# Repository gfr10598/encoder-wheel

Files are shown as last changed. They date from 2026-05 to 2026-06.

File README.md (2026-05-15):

# Encoder Wheel

A parametric design repository for **magnetic rotary encoder wheels**.

The wheel holds *N* (a multiple of 12) rectangular permanent magnets in a
radial arrangement.  A Hall-effect sensor reads the alternating North/South
poles as the wheel rotates, giving a high-resolution angle or speed signal.

This repository provides Python scripts that generate ready-to-fabricate files
for three different manufacturing processes:

| Fabrication method | Script | Output format |
|---|---|---|
| **Laser cutter** | `scripts/cad/generate_laser.py` | SVG |
| **CNC mill** | `scripts/cad/generate_cnc.py` | DXF (R12) |
| **3-D printer** | `scripts/cad/generate_3d.py` | OpenSCAD (`.scad`) |

All scripts share a common geometry core (`scripts/common.py`) and accept the
same magnet-dimension and pole-count parameters, so you can swap fabrication
methods without re-calculating anything.

---

## Contents

```raw
encoder-wheel/
├── scripts/
│   ├── common.py                       shared geometry calculations
│   ├── common_config.py                shared config loading
│   ├── cad/                            CAD fabrication generators
│   │   ├── generate_laser.py           → SVG for laser cutting
│   │   ├── generate_cnc.py             → DXF for CNC milling
│   │   ├── generate_3d.py              → OpenSCAD for 3-D printing
│   │   └── generate_half_ring_docs.py  → SVG design-reference documentation
│   └── magnetic/                       magnetic field analysis & validation
│       ├── magnet.py                   MagnetCorners class & Aharoni formula
│       ├── test_kj_validation.py       K&J website benchmark (1.6% error)
│       ├── test_single_magnet_vs_kj.py validation test harness
│       └── simulation.py               full encoder wheel simulation
├── AGENTS.md                       AI-agent-facing design notes
├── examples/
│   ├── encoder_wheel_12pole_laser.svg
│   ├── encoder_wheel_24pole_laser.svg
│   ├── encoder_wheel_108pole_laser.svg
│   ├── encoder_wheel_12pole_cnc.dxf
│   ├── encoder_wheel_108pole_cnc.dxf
│   ├── encoder_wheel_12pole_3d.scad        (back plate + tabs)
│   ├── encoder_wheel_108pole_3d.scad       (back plate + tabs)
│   ├── encoder_wheel_12pole_3d_frontface.scad
│   └── encoder_wheel_12pole_3d_steelclip.scad
└── images/

    ├── top_view.svg```

    ├── cross_section.svg    └── half_ring_over_magnets_perspective.svg

    ├── geometry.svg    ├── half_ring_over_magnets_top_view.svg
    ├── half_ring_over_magnets_cross_section.svg

---

## Half-ring cover design notes

The repository also includes a documentation-only capture of the requested
**10 in half-ring over magnets** concept for future CAD work:

- agent/design notes: [`AGENTS.md`](AGENTS.md)
- generated reference drawings:
  - `images/half_ring_over_magnets_cross_section.svg`
  - `images/half_ring_over_magnets_top_view.svg`
  - `images/half_ring_over_magnets_perspective.svg`

Regenerate those drawings with:

```bash
python scripts/generate_half_ring_docs.py
```

---

## Design Overview

### Magnet arrangement

Each magnet is a rectangular block:

```raw
  magnet_length  (L)  — radial extent    (default 20 mm)
  magnet_width   (w)  — tangential extent (default  5 mm)
  magnet_thickness(t) — axial extent     (default  2 mm)
```

The magnets are placed radially around a central axis.  Their 5 mm
(tangential) faces point around the wheel; their 20 mm (radial) faces point
outward from the centre.

Top view of a 12-magnet encoder wheel

*Alternating blue shades represent North (lighter) and South (darker) poles.
Red dots mark the **touching inner corners**.*

### The inner-corners-touching condition

A key design constraint is that **the inner corner of each magnet meets the
inner corner of the adjacent magnet**.  This means:

- There is zero gap between adjacent magnets at the inner radius.
- The inner rim is structurally disconnected from the outer ring — the only
  structural connection between the outer ring and the inner area is through
  the triangular "spokes" between adjacent magnet slots.

Inner-corners-touching geometry

The minimum inner radius is derived by requiring the inner-CW corner of magnet
*i* to be the same Cartesian point as the inner-CCW corner of magnet *i+1*:

```raw
r_inner_min = (w / 2) / tan(π / N)
```

| N (poles) | r\_inner\_min | r\_outer (r\_inner + 20 mm) | Disc ⌀ (+3 mm margin) |
|---|---|---|---|
| 12 | 9.33 mm | 29.33 mm | 64.7 mm |
| 24 | 18.99 mm | 38.99 mm | 84.0 mm |
| 36 | 28.69 mm | 48.69 mm | 103.4 mm |
| 48 | 38.41 mm | 58.41 mm | 122.8 mm |
| 108 | 85.92 mm | 105.92 mm | 217.8 mm |

You can specify a larger `--inner-radius` to increase the disc size (e.g., to
fit a specific shaft hub), but you cannot go smaller than `r_inner_min`.

---

## Quick Start

No external Python packages are required — the scripts use only the standard
library.

```bash
# Laser cutter SVG (12 poles, default parameters)
python scripts/generate_laser.py --output my_wheel.svg

# CNC milling DXF
python scripts/generate_cnc.py --output my_wheel.dxf

# 3-D printing OpenSCAD (with retaining tabs and back plate)
python scripts/generate_3d.py --output my_wheel.scad
```

Open the resulting files in your favourite CAD / laser / slicer tool.

---

## Parameters

All three scripts accept the following common parameters:

| Flag | Default | Description |
|---|---|---|
| `--n-magnets N` | `12` | Number of magnets (must be a multiple of 12) |
| `--length L` | `20.0` | Magnet radial length (mm) |
| `--width W` | `5.0` | Magnet tangential width (mm) |
| `--thickness T` | `2.0` | Magnet axial thickness (mm) |
| `--inner-radius R` | *(minimum)* | Inner radius (mm); computed if omitted |
| `--margin M` | `3.0` | Extra material beyond the outer magnet tips (mm) |
| `--center-bore R` | `5.0` | Central shaft bore radius (mm) |

### Laser cutter (`generate_laser.py`)

| Flag | Default | Description |
|---|---|---|
| `--kerf K` | `0.1` | Kerf compensation per side (mm) — expands each slot |
| `--no-center-hole` | — | Omit the central shaft hole |
| `--center-hole-radius R` | `5.0` | Shaft hole radius (mm) |

**Sheet thickness** should match `--thickness` (the magnet axial dimension).
Use 2 mm acrylic or plywood.

The SVG uses two colours:
- **Red** (`#FF0000`) — through-cut paths
- **Blue** (`#0000FF`, dashed) — score / engrave lines

### CNC mill (`generate_cnc.py`)

| Flag | Default | Description |
|---|---|---|
| `--clearance C` | `0.1` | Per-side pocket clearance for easy fit (mm) |

The DXF output contains four layers:

| Layer | Description |
|---|---|
| `BOUNDARY` | Outer disc circle — profile cut |
| `BORE` | Central shaft bore — profile cut or drill |
| `POCKETS` | Magnet pocket rectangles — machine as pockets to `--thickness` depth |
| `REFERENCE` | Inner radius circle — do not cut, reference only |

Machine the `POCKETS` first, then `BORE`, then `BOUNDARY`.

### 3-D printer (`generate_3d.py`)

The 3-D printing script has several additional options for the wheel frame
construction:

Cross-section of 3D printing options

#### Retaining tabs (`--tabs` / `--no-tabs`, default: on)

Small overhanging lips at the inner- and outer-radial ends of each pocket
opening.  They overhang the pocket by `--tab-overhang` mm so that a magnet
snapped in from above is held without adhesive.

| Flag | Default | Description |
|---|---|---|
| `--tabs` | *(on)* | Add retaining-tab overhangs |
| `--no-tabs` | — | Omit retaining tabs (glue or press-fit magnets) |
| `--tab-width W` | `1.5` | Radial width of each tab (mm) |
| `--tab-overhang D` | `0.6` | Overhang depth of each tab into pocket (mm) |

> **Tip**: Print with the pocket face upward.  The tabs are short bridging
> spans that FDM printers handle without support.

#### Back plate (`--back-plate` / `--no-back-plate`, default: on)

A solid printed disc behind the magnet pockets seals the back face.

| Flag | Default | Description |
|---|---|---|
| `--back-plate` | *(on)* | Include a printed back disc |
| `--no-back-plate` | — | Open back face (magnets accessible from both sides) |
| `--back-thickness T` | `1.5` | Back plate thickness (mm) |

#### Smooth front face (`--front-face` / `--no-front-face`, default: off)

A thin solid skin covers the front (sensor-facing) side of the wheel.

| Flag | Default | Description |
|---|---|---|
| `--front-face` | — | Add a smooth front face over the magnets |
| `--no-front-face` | *(on)* | Leave front face open |
| `--front-thickness T` | `0.8` | Front face thickness (mm) |

> Use `--front-face` when you want a smooth, consistent air-gap distance to
> your Hall-effect sensor array.

#### Steel backing-plate clips (`--steel-clip` / `--no-steel-clip`, default: off)

Adds rectangular notch features around the outer rim so that a separate thin
**steel disc** can snap into the frame from the back.  The steel disc acts as a
**magnetic flux-return** path, concentrating the field toward the sensor face
and significantly improving signal strength.

| Flag | Default | Description |
|---|---|---|
| `--steel-clip` | — | Add steel-plate clip slots in the outer rim |
| `--no-steel-clip` | *(on)* | No clip slots |
| `--n-clips N` | `6` | Number of clip slots (evenly spaced) |
| `--clip-width W` | `3.0` | Clip slot width (mm) |
| `--clip-depth D` | `1.2` | Clip slot radial depth (mm) |
| `--clip-height H` | `1.0` | Clip slot axial height (mm) |

Use `--steel-clip --no-back-plate` to leave the back fully open for the steel
disc.  Cut or stamp the steel disc to the same outer diameter as the frame.

---

## Fabrication Notes

### Laser cutting

1. Set your material to a sheet whose thickness matches the magnet axial
   dimension (typically 2 mm acrylic).
2. Import the SVG into your laser software.  The file dimensions are in mm.
3. Assign the **red** lines as *cut* and the **blue** dashed lines as *engrave*
   (or simply ignore blue if you do not want the reference markings).
4. After cutting, slide the magnets into the slots, alternating N/S poles.
   A thin drop of super-glue holds each magnet in place.

### CNC milling

1. Open the DXF in your CAM software (Fusion 360, Mastercam, Vectric, etc.).
2. Machine the **POCKETS** layer as 2-D pockets to `--thickness` depth.
3. Drill or bore the **BORE** layer as a hole through the full material
   thickness.
4. Profile-cut the **BOUNDARY** circle last, with tabs to keep the disc in
   the fixture.
5. Suitable materials: aluminium, brass, Delrin/POM, HDPE, or steel.
   For best magnetic signal, use **non-magnetic** material (aluminium,
   brass, plastic).

### 3-D printing

1. Open the `.scad` file in OpenSCAD.  Press `F6` to render, then
   `File → Export → STL` to export for slicing.
2. Print flat on the bed (the wheel lies in the XY plane, shaft bore facing
   up).
3. Layer height 0.15–0.20 mm for good pocket accuracy.
4. The retaining tabs rely on bridging; no supports are needed if the tab
   overhang is ≤ 1 mm.
5. Insert magnets by pressing them in from above (snapping past the tabs), or
   slide them in radially before adding any front cover.

---

## Examples

Pre-generated example files are in the `examples/` directory:

| File | Description |
|---|---|
| `encoder_wheel_12pole_laser.svg` | 12-pole laser template |
| `encoder_wheel_24pole_laser.svg` | 24-pole laser template |
| `encoder_wheel_108pole_laser.svg` | 108-pole laser template |
| `encoder_wheel_12pole_cnc.dxf` | 12-pole CNC DXF |
| `encoder_wheel_108pole_cnc.dxf` | 108-pole CNC DXF |
| `encoder_wheel_12pole_3d.scad` | 12-pole 3-D print (back plate + tabs) |
| `encoder_wheel_108pole_3d.scad` | 108-pole 3-D print (back plate + tabs) |
| `encoder_wheel_12pole_3d_frontface.scad` | 12-pole with smooth front face |
| `encoder_wheel_12pole_3d_steelclip.scad` | 12-pole with steel-clip slots, no back plate |

Regenerate any file by running the corresponding script with the desired
parameters.

---

## Magnet sourcing

Standard rectangular neodymium magnets in 20 × 5 × 2 mm (N42 or N52 grade)
are widely available and match the default parameters exactly.  Ensure you
order matched pairs or a set with alternating polarity markings if you want
the poles pre-sorted.

---

## Licence

[MIT](LICENSE) — free to use, modify, and redistribute.

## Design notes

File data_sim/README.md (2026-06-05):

# Encoder Wheel Compression Analysis

Magnetic encoder simulation and signal compression framework for quadrature encoder signals.

## Overview

This directory contains analysis and implementation of compression algorithms for 18-pole quadrature encoder signals sampled at 5 kHz with Gaussian noise (0.8 LSB RMS).

**Physical Model:**
- 1-meter pendulum swinging through 360° with impact event
- Simulates realistic motion with slowly-varying angular velocity on constrained ellipse
- 18-pole pairs → 18 complete magnetic cycles per rotation
- X channel: sin(18θ), Y channel: cos(18θ), amplitude ±2047 (16-bit signed)

## Key Findings

### Signal Statistics
- **Position (raw):** X, Y ∈ [−2049, +2049], σ ≈ 1455 LSB
- **Velocity (delta):** dx, dy mean ≈ 0, std ≈ 16.6 LSB, range [−48, +47]
- **Acceleration (delta-delta):** ddx, ddy std ≈ 2.2 LSB, range [−8, +8]

### Compression Results

#### 1. **Velocity Predictor (EMA, α=0.25)** — CURRENT BASELINE
- **Residuals:** σ_x ≈ 1.91 LSB, σ_y ≈ 1.91 LSB
- **Encoding:** 4 bits per variable (±8 range fits in signed 4-bit)
- **Total:** 8.16 bits/sample (4-bit packed + 1.14% sync overhead)
- **Compression:** 3.9× vs uncompressed (32 → 8.16 bits/sample)
- **Data reduction:** 74.5%

#### 2. **Quadratic Predictor (pos + vel + accel)**
- **Residuals:** σ_x ≈ 3.07 LSB, σ_y ≈ 3.08 LSB
- **Issue:** Acceleration amplifies noise (1.9 → 3.1 LSB)
- **2-sigma coverage:** 93.2% (worse than velocity)
- **Verdict:** Physics-limited; velocity is superior

#### 3. **Coupled Linear Predictors** (NEW — see `coupled_predictor.ipynb`)
- **Method 2a: Orthogonal Decomposition (v + a/2)**
  - Tangential + centripetal acceleration model
  - No trig functions; operates in linear domain
- **Method 2b: Angular Velocity Predictor** ⭐
  - Extracts instantaneous angular velocity: $\omega = \frac{x \cdot dy - y \cdot dx}{x^2 + y^2}$
  - Predicts velocity rotation via 2×2 small-angle matrix
  - Geometry-aware; exploits ellipse constraint without trig
  - Adapts $\hat{\omega}$ from residuals
- **Method 2c: Joint Coupling Matrix (2×2)**
  - Learns general affine transformation on velocity vector
  - Exploits X-Y correlation in elliptical motion
  - Adaptive learning with history buffer

## Files

### Notebooks
- **`residual_analysis.ipynb`** — Main analysis pipeline
  - Phase-dependent analysis (signed mean/std by velocity magnitude)
  - Quantization and clipping validation
  - Protocol encoder/decoder metrics
  - Velocity, quadratic, and delta-delta predictors
  - 4-bit packed encoding with escape codes
  
- **`coupled_predictor.ipynb`** (NEW) — Coupled predictor exploration
  - Orthogonal decomposition (tangential + centripetal)
  - Joint matrix coupling analysis
  - Side-by-side comparison plots

### Simulation Code
- **`sim.py`** — Reference implementation
  - `PendulumSimulator`: Physical model with noise injection
  - `VelocityPredictor`: EMA-based velocity estimation (current best)
  - `VelocityEncoder` / `VelocityDecoder`: Protocol codecs (0xFE escapes, 4-bit quantization)
  - `LinearMatrixPredictor`: General affine transformation
  - `DeltaDeltaEncoder`: Acceleration-based alternative
  - `s16()`: Signed 16-bit wraparound helper

## Encoding Architecture

### Current: 4-Bit Packed (8.16 bits/sample)

**Standard frame (1 byte per (X, Y) pair):**
```raw
Byte: [X_nibble | Y_nibble]
      [4-bit signed X | 4-bit signed Y]
Range: {−8..+7} × {−8..+7}
Coverage: 100% of velocity residuals
```

**Escape codes (1 marker + extended):**
- Reserved for future multi-frame state or extended dynamic range
- Currently unused (all residuals fit in ±8)

**Sync frames (every 100 msec @ 5 kHz = 500 samples):**
- **0xF0** (Position sync): 1 byte header + 2 bytes per axis = 5 bytes
- **0xF1** (State sync): 1 byte header + 14 bytes payload = 15 bytes
- Overhead: ~1.14% of total bytes

### Metrics
- **Fundamental:** σ_x = σ_y = 1.91 LSB
- **2-sigma coverage:** 95%+ (reliable prediction window)
- **Axis-alignment frequency:** 18.44% (one axis ≈ 0, other large)
- **Correlation (X, Y residuals):** −0.001 (independent)

## Validation

```bash
# Check Python syntax
python -m py_compile scripts/*.py data_sim/sim.py

# Run main analysis
jupyter notebook data_sim/residual_analysis.ipynb

# Run coupled predictor exploration
jupyter notebook data_sim/coupled_predictor.ipynb
```

## Design Decisions

1. **4-bit over tiers:** Simpler than 3-tier protocol; all residuals fit perfectly
2. **Velocity over acceleration:** 1.91 LSB << 3.07 LSB; noise amplification makes acceleration inferior
3. **Independent X, Y encoding:** Correlation ≈ 0; no savings from joint quantization
4. **Int16 arithmetic throughout:** All computations use signed 16-bit (no floating point in critical path)
5. **EMA smoothing (α=0.25):** Balances responsiveness and noise rejection; convergence in ~12 samples

## Next Steps

1. **Evaluate coupled predictors** in `coupled_predictor.ipynb` for potential sub-1.91 LSB residuals
2. **Consider adaptive quantization** if motion changes character (e.g., impact events)
3. **Implement hardware-efficient codec** using 4-bit packed + escape for production
4. **Validate decoder reconstruction error** on full 100+ millisecond traces

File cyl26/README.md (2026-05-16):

# cyl26 — Cylindrical Magnet Ring

PETG sleeve that mounts on an existing 4-inch cast iron shaft and holds 26 NdFeB N52 magnets (20 × 10 × 5 mm) on its outer surface.

## Assembly

The ring is printed as **two identical halves**.  The second half is the same print, flipped 180° around the shaft axis (Z).  The seam is at θ = 0° / 180°.

## Seam Joint

Each half has an **S-curve tongue** on one tangential end and a matching **S-curve groove** on the other.  When the two halves are placed around the shaft the tongue of each half slides axially (Z) into the groove of the other.

The S-profile is two tangent circular arcs (radius ≈ 0.45 mm) that create a smooth interlocking shape with no sharp corners.  Both features fit within the ~3 mm tangential gap between adjacent magnet pockets and span the full 5 mm radial wall thickness.

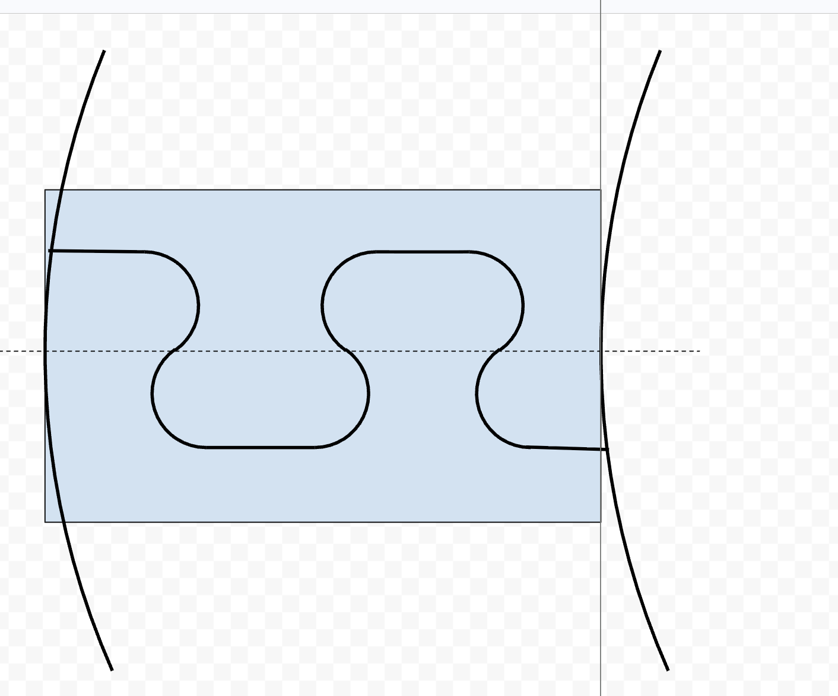
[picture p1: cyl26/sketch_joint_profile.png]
S-joint cross-section sketch


*Dashed line = Y = 0 seam plane.  Blue box = ~3 mm × 5 mm available area between magnet pockets.
Left feature = groove (pocket cut into body).  Right feature = tongue (protrudes past seam).*

## Key dimensions (from `config.json`)

| Parameter | Value |
|---|---|
| Shaft OD (reference) | 101.6 mm |
| Bore clearance | 0.3 mm |
| Wall thickness | 5.0 mm |
| Sleeve length | 30.0 mm |
| Joint arc radius | 0.45 mm |
| Joint clearance (sliding fit) | 0.15 mm |

## Files

| File | Purpose |
|---|---|
| `config.json` | All geometry parameters |
| `generate.py` | build123d model + OCP Viewer entry point |
| `sketch_joint_profile.png` | Hand sketch of S-joint cross-section |

## Running

```bash
.venv/bin/python cyl26/generate.py
```

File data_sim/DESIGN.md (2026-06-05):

# 18 Pole-Pair Rotary Encoder: Sync-Framed Base-39 Dual-Axis Tracking Protocol

This protocol specifies an ultra-low-bandwidth, zero-latency streaming compression architecture for an inverted pendulum tracking system utilizing an 18 pole-pair magnetic rotary encoder sampled at 5 kHz.

## 1. System Constants & Parameters
* Sensor Range: 12-bit Peak-to-Peak (Peak vector radius R ≈ 1500 LSB)
* Sensor Noise Floor: σ = 0.8 LSB
* Dynamics: Max rotational velocity ≈ 7 rad/sec (≈ 126 rad/sec electrical)
* Sampling Interval: dt = 200 μs (5 kHz)
* Pole-Pair Multiplier: 18 electrical cycles per mechanical revolution
* Predictor Architecture: Dual 1 kHz single-pole Low-Pass Filters tracking both Angular Velocity (filtered_omega) and Radial Velocity (filtered_dr) to natively absorb uncalibrated ellipse distortions.

---

## 2. Normal Tracking Block (Base-39 Matrix)
Normal data samples are packed into rigid groups of 3 consecutive time steps. Each individual time sample isolates a joint token combining radial and non-linear tangential innovations.

### Innovation Alphabet Sizes
* Radial Component (ε_R): 3 States (-1, 0, +1) - Kept tight via active radial velocity tracking.
* Tangential Component (ε_T): 13 States (0, ±1, ±2, ±3, ±4, ±6, ±9)
* Total Joint Tokens per Sample: 3 × 13 = 39 states (Indices 0 to 38)

### Base-39 Word Combination Math
Three sequential tokens (T₁, T₂, T₃) are compressed into a single 16-bit integer container using base-39 positional multiplication:
Word_Value = ((T_1 * 39) + T_2) * 39 + T_3

* Normal Code Range: 0 to 59,318 (0x0000 to 0xE7B6)
* Transmission Footprint: 2 bytes per 3 samples (5.33 bits per sample pair)
* Byte 0 Constraint: The first byte of any normal data block can only ever range from 0x00 to 0xE7.

---

## 3. Inline Zero-Crossing Sync Frame
The moment the tracking vector executes a cosine channel zero-crossing (crosses the y-axis), the encoder halts normal execution, flushes any partial token combinations, and immediately transmits a 6-byte (48-bit) Zero-Knowledge Sync Block in Big Endian / Network Byte Order.

### 6-Byte Serial Byte Layout
Byte 0: Word 1 High Byte [Ranges from 0xE7 to 0xF7]
Byte 1: Word 1 Low Byte  [Word 1 = 59,320 + Signed 12-bit Sine Value biased by +2048]
Byte 2: Payload Byte     [Upper 5 bits = 0x1A Fingerprint, Lower 3 bits = Coarse Radial Velocity]
Byte 3: Cosine 1 Sample  [8-bit signed int8_t]
Byte 4: Cosine 2 Sample  [8-bit signed int8_t]
Byte 5: Cosine 3 Sample  [8-bit signed int8_t]

---

## 4. Framing Inference and Look-Ahead Byte Sync
When the decoder cold-boots mid-fall or emerges from a violent 10 ms mechanical noise burst, it scans incoming bytes sequentially using a sliding window parser.

Framing alignment is achieved by looking for the explicit signature of the 0x1A Fingerprint:
1. Scan for a byte configuration matching the pattern 11010_xxx (where the upper 5 bits equal 0x1A).
2. Evaluate the 16-bit word located two positions backward in history (Word 1 position).
3. If that backward word sits within the valid sync range of 59,320 to 63,415 (0xE7B8 to 0xF7B7), a valid sync frame match is confirmed.
4. The decoder extracts the 12-bit signed Sine axis, captures the three raw cosine values to calculate the velocity slope, re-seeds both the angular and radial tracking filters, and instantly achieves perfect tracking synchronization within a 2-word look-ahead window.

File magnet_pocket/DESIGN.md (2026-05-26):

# Magnet Pocket Cell — Design Document

## Overview

A parametric single-magnet holder cell that assembles into a closed ring.
Each cell holds one rectangular NdFeB magnet that slides radially inward through the
bore opening and lies flush with the inner diameter (ID) surface.

Adjacent cells connect along their shared tangential walls via a **comb interlock**:
the wall carries a set of alternating teeth, with odd-indexed teeth belonging to the
left cell and even-indexed teeth belonging to the right cell.  Each tooth tip carries
a snap overhang so the ring self-locks when assembled.

Both the individual cell and the complete ring are required to have **C2 symmetry**
(invariance under 180° rotation about the appropriate axis).

---

## Coordinate system

Cell-local frame, origin at the geometric centre of the cell body:

```raw
         Z (axial, along ring axis)
         |      +Y (tangential, direction of increasing angle)
         |    /
         |  /
         +----------->  +X (radial, outward from ring centre)
```

Ring-global frame: ring axis is global Z; a cell at angle theta has its +X aligned
with the outward radial direction at that angle.

---

## Cell body geometry

Each cell is a trapezoidal-prism wedge (constant angle alpha) before pocketing.

| Quantity | Symbol | Expression | Notes |
|---|---|---|---|
| Inner radius | R_i | `ID_mm / 2` | flush with bore |
| Outer radius | R_o | `R_i + thickness_mm` | outer surface |
| Angular pitch | alpha | `360 deg / magnet_count` | full-ring pitch |
| Arc width at bore | W_i | `pi * ID_mm / magnet_count` | smallest cross-section |
| Cell axial height | H | `magnet.axial_mm + 2 * end_face_mm` | |

The cell spans +/-alpha/2 about its centre angle.

---

## Magnet pocket and retention snap

### Pocket geometry

The magnet slides **radially inward** through the bore face and comes to rest flush
with the ID surface (inner face of magnet = inner face of cell at R_i).

```raw
  <- radial (X) ->

  R_i              R_i + radial_mm     R_o
   |<---- magnet ----->|<-- outer wall -->|
   |  (flush with bore)|                 |
```

| Feature | Expression |
|---|---|
| Pocket inner face | R_i (flush with bore) |
| Pocket depth (radial) | `magnet.radial_mm + clearance_mm` |
| Outer wall thickness | `thickness_mm - magnet.radial_mm - clearance_mm` |
| Pocket tangential width | `magnet.tangential_mm + clearance_mm` |
| Pocket axial height | `magnet.axial_mm + clearance_mm` |

The pocket has five closed faces (outer/top/bottom/left/right) and one open face at
the bore.  Pocket edges are filleted:

- Edges parallel to Z (axial): radius `magnet.edge_radius_axial_mm`
- All other edges: radius `magnet.edge_radius_other_mm`

### Bore-side retention snap

Because the magnet is flush with the bore, the only radially accessible feature is
the **rounded corner** on the inner edge of the magnet.  Retention lips project
slightly inward (-X) from the bore opening, engaging the magnet's
`edge_radius_other_mm` radius as the magnet snaps in.

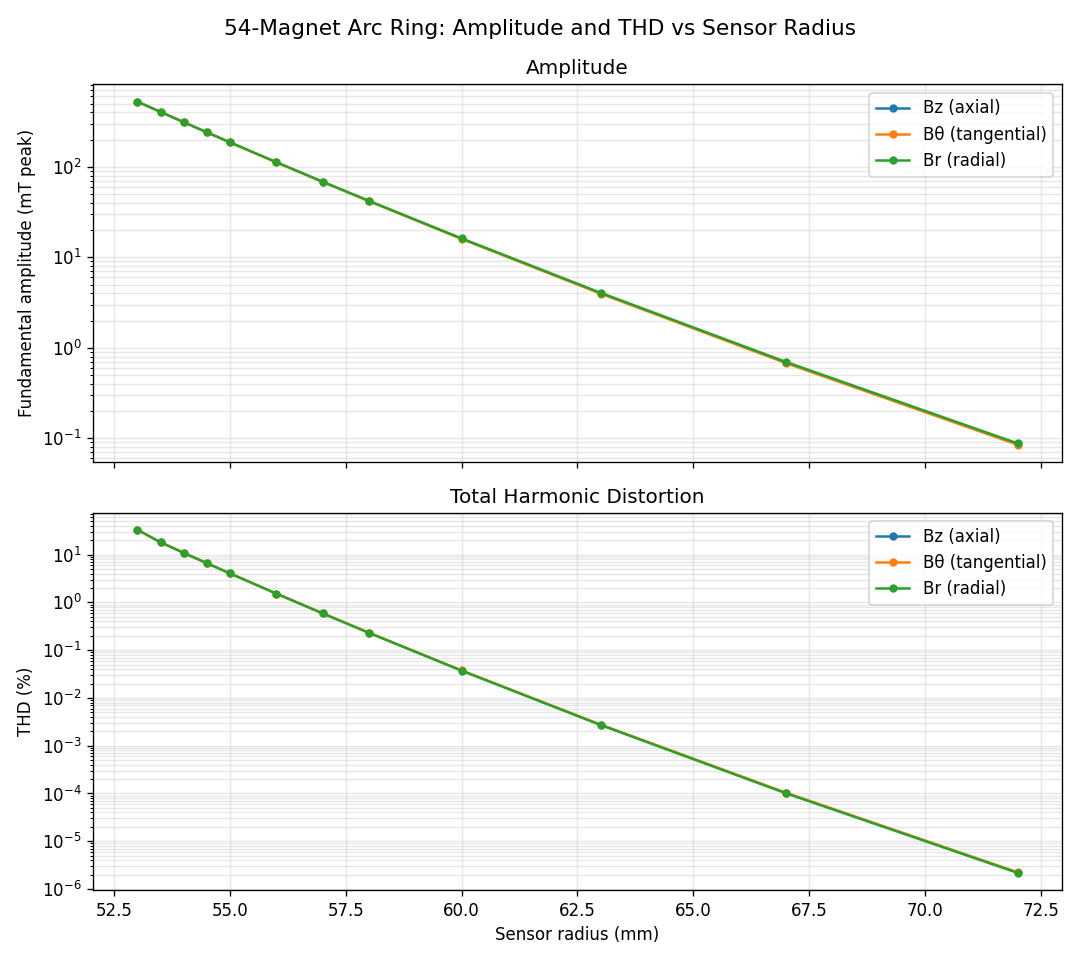
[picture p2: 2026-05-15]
scripts/magnetic/54/54mag_amplitude_thd.png

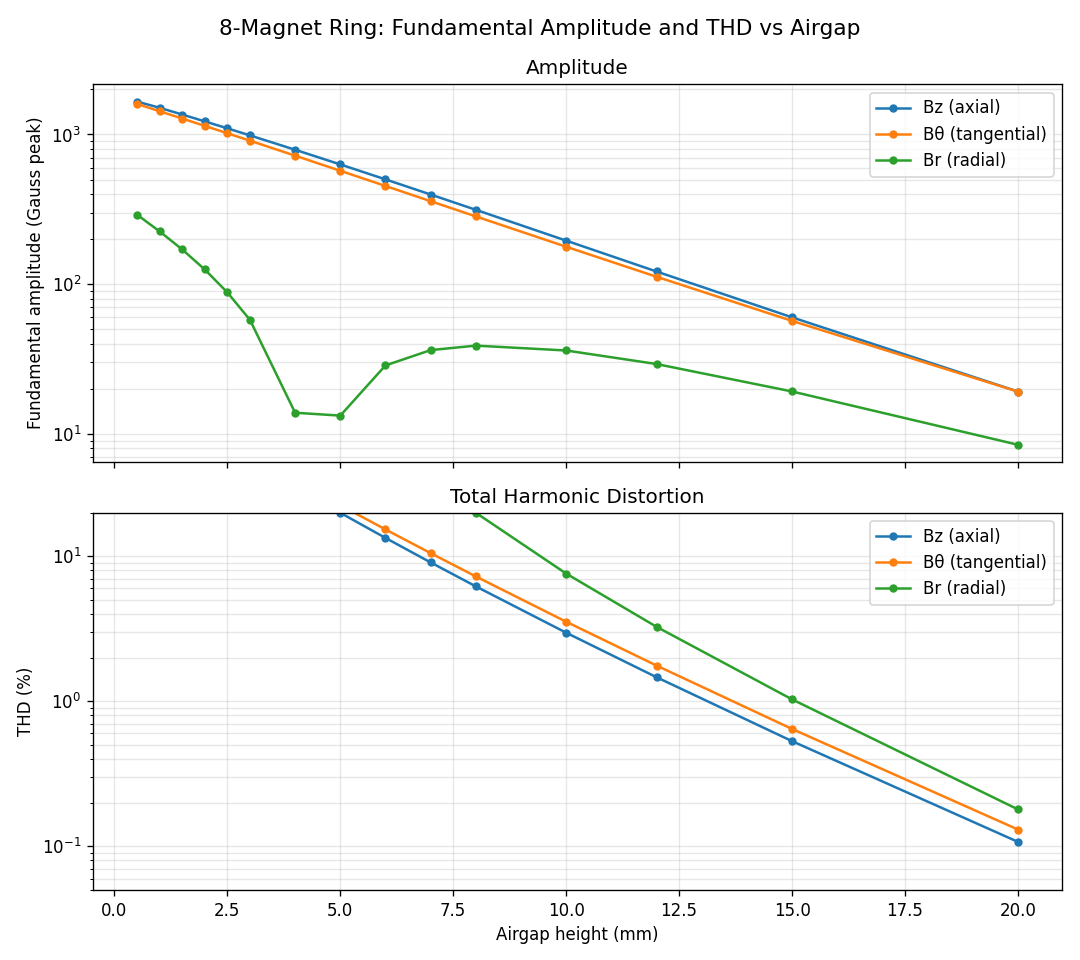
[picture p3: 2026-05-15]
scripts/magnetic/8/8mag_amplitude_thd.png

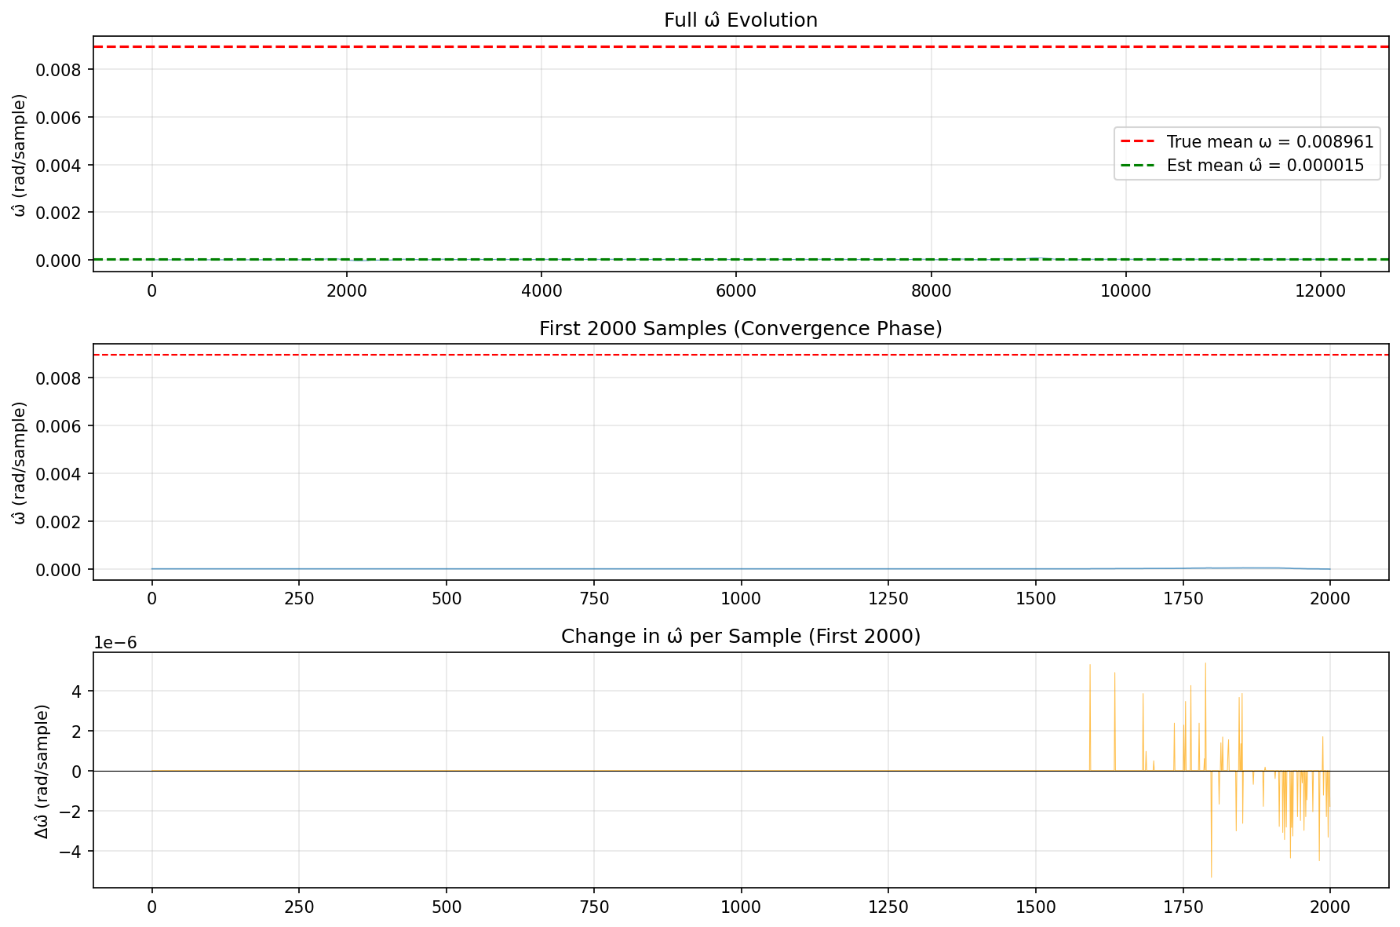
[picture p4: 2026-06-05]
data_sim/omega_convergence_analysis.png

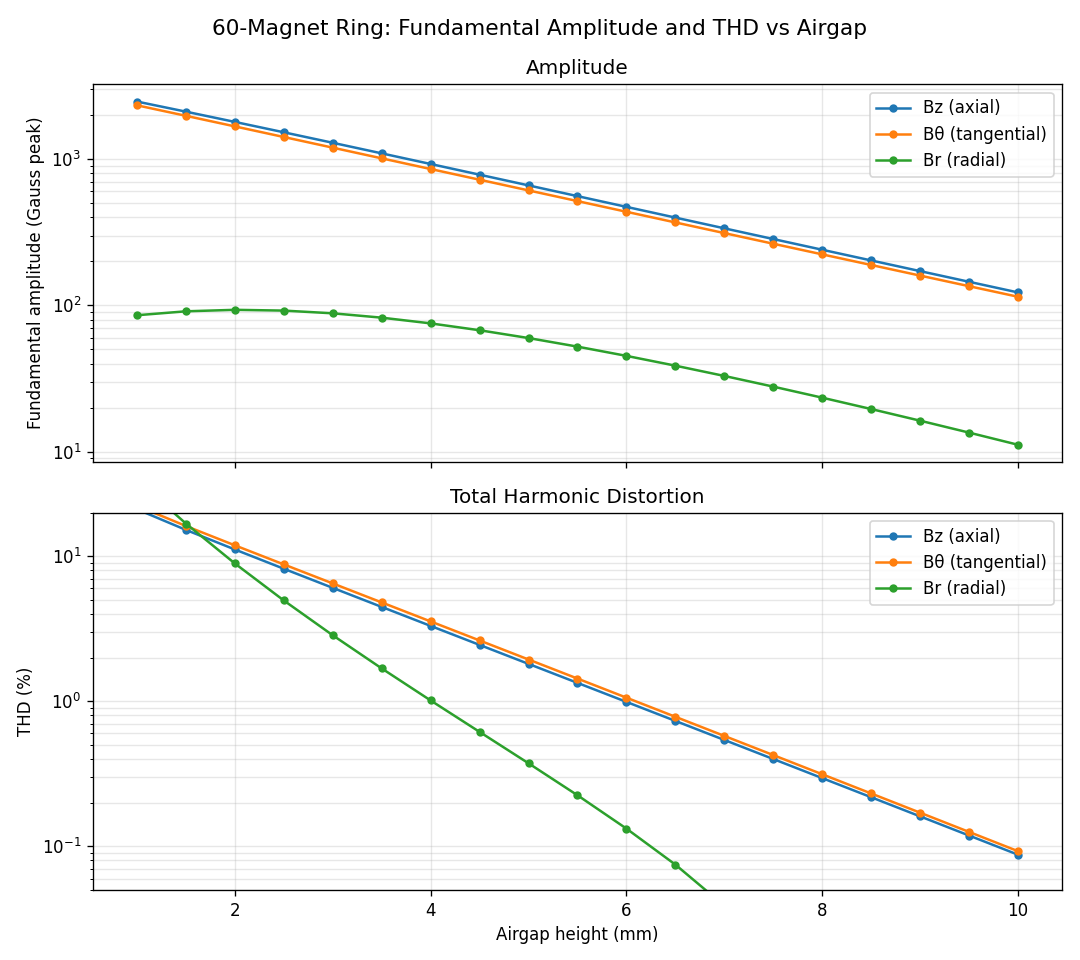
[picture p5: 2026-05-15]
scripts/magnetic/60/60mag_amplitude_thd.png

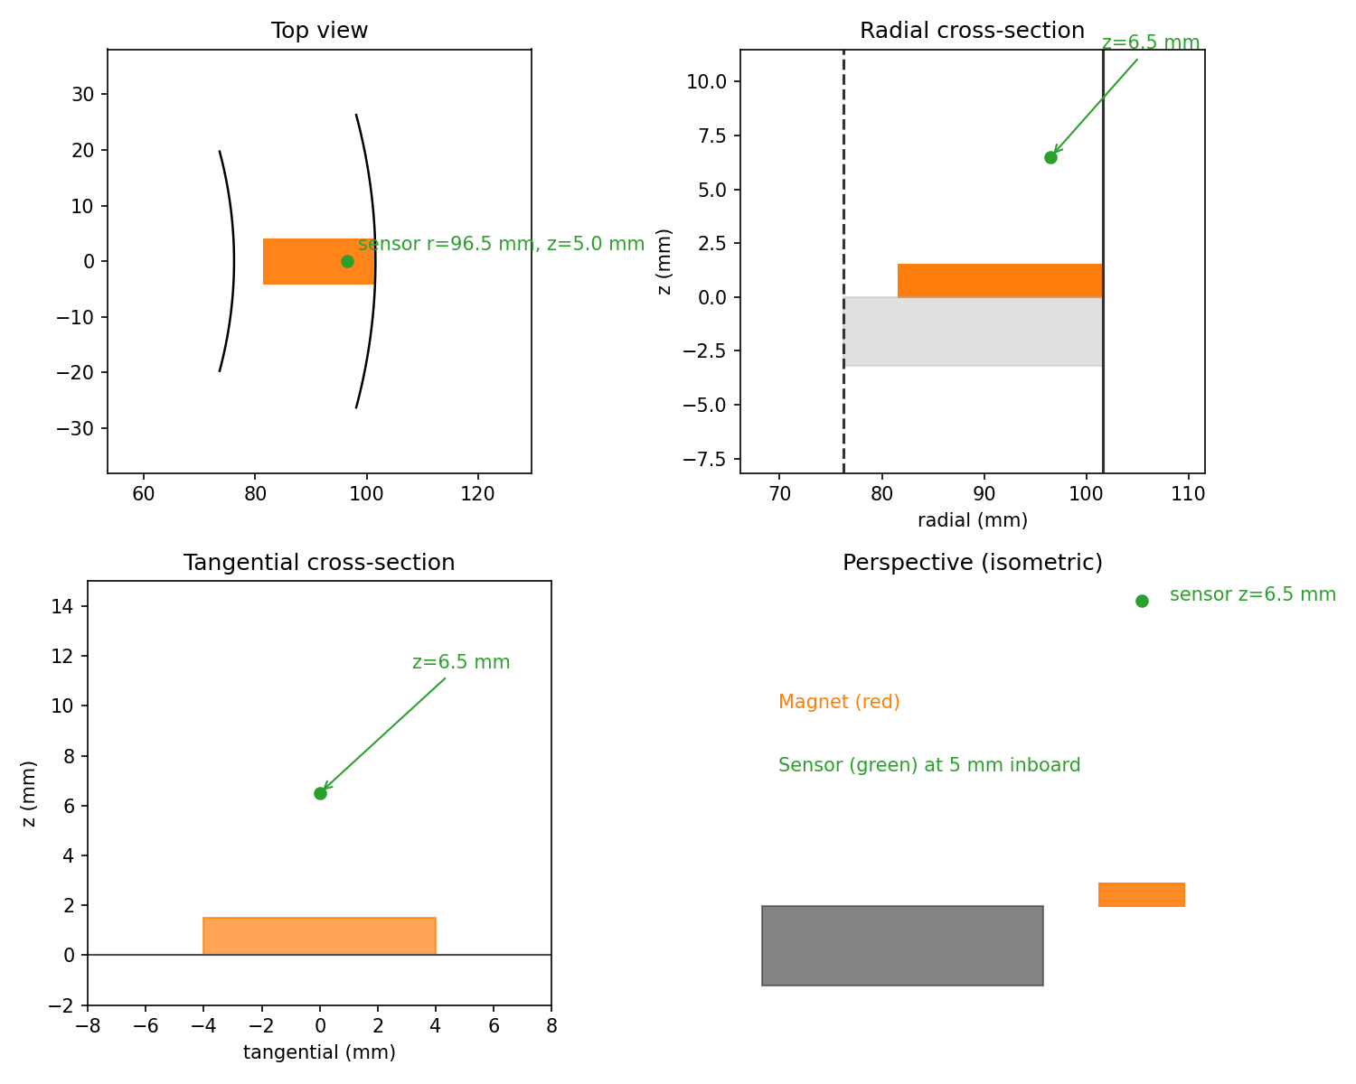
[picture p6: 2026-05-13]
examples/plots/sensor_diagram.png

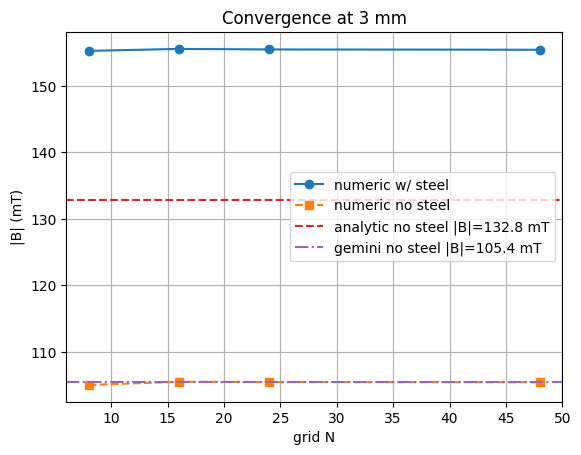
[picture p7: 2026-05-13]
examples/plots/diagnostics_convergence_3mm.png

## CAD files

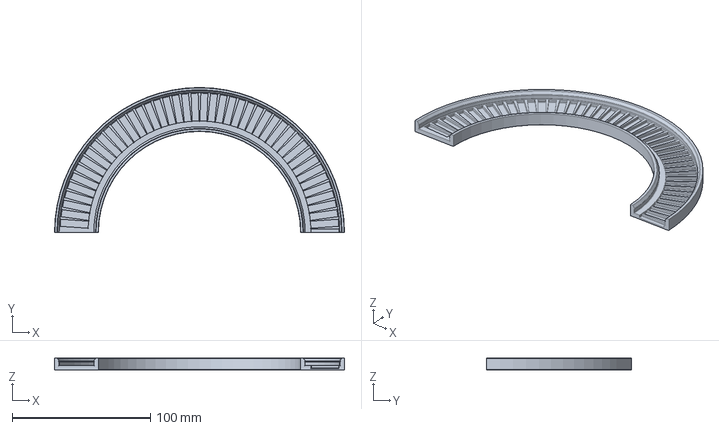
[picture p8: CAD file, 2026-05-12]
examples/half_ring_cover.step
209.6 x 104.8 x 8.47 mm

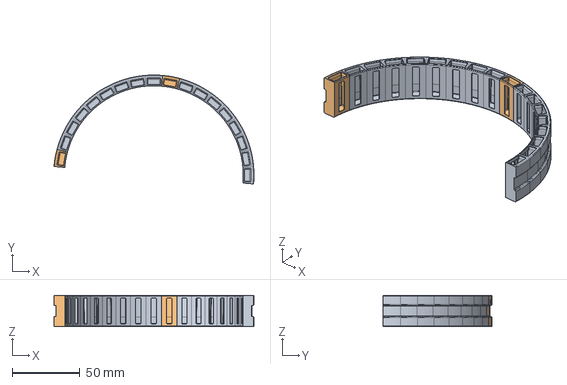
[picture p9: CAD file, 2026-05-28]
magnet_pocket/output/arc18_36.step
148.1 x 80.7 x 23.0 mm

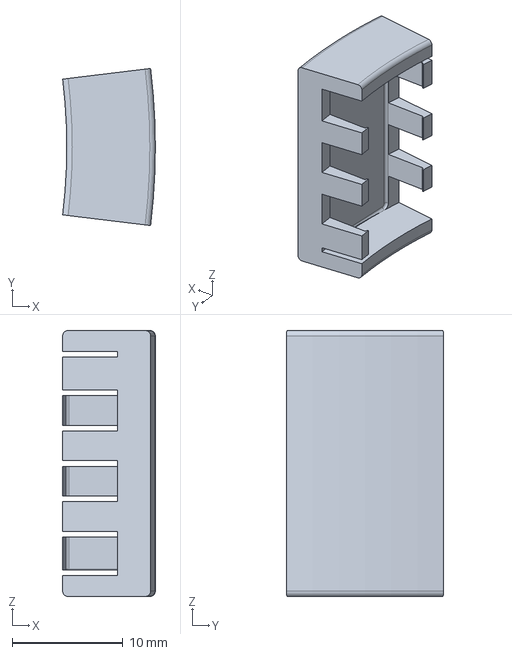
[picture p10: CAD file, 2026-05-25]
magnet_pocket/tooth-output/cell.step
8.37 x 14.2 x 24.0 mm

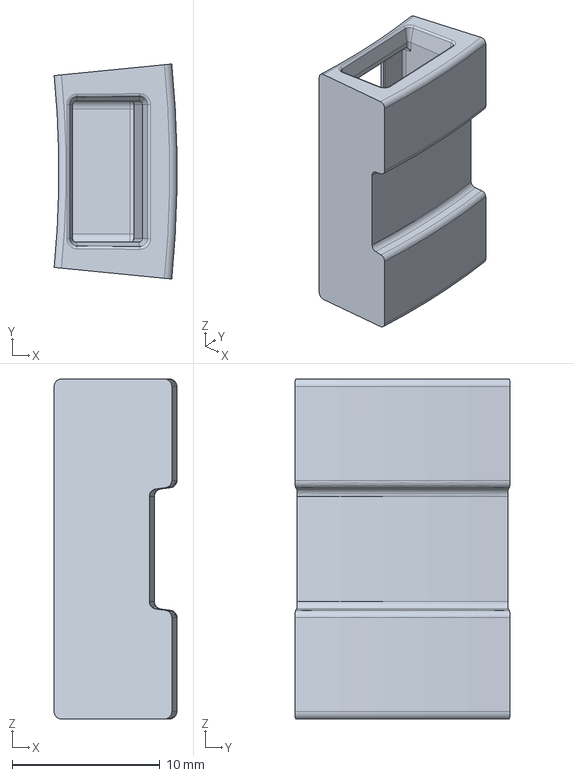
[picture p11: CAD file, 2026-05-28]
magnet_pocket/output/cell.step
8.31 x 14.5 x 23.0 mm

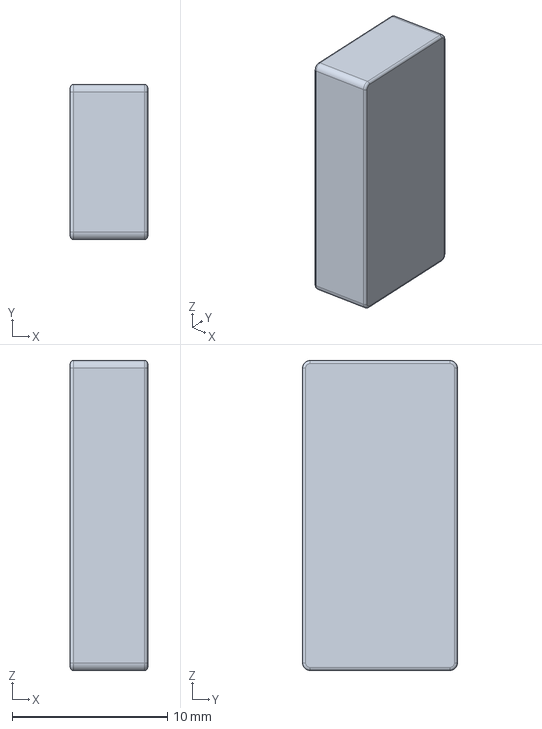
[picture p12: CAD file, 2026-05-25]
magnet_pocket/tooth-output/magnet.step
5.00 x 10.0 x 20.0 mm

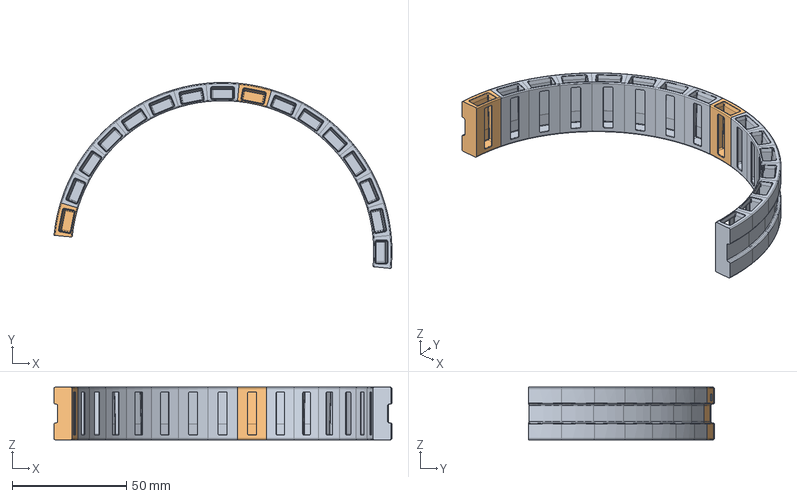
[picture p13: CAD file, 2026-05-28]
magnet_pocket/output/arc16_32.step
148.0 x 81.5 x 23.0 mm

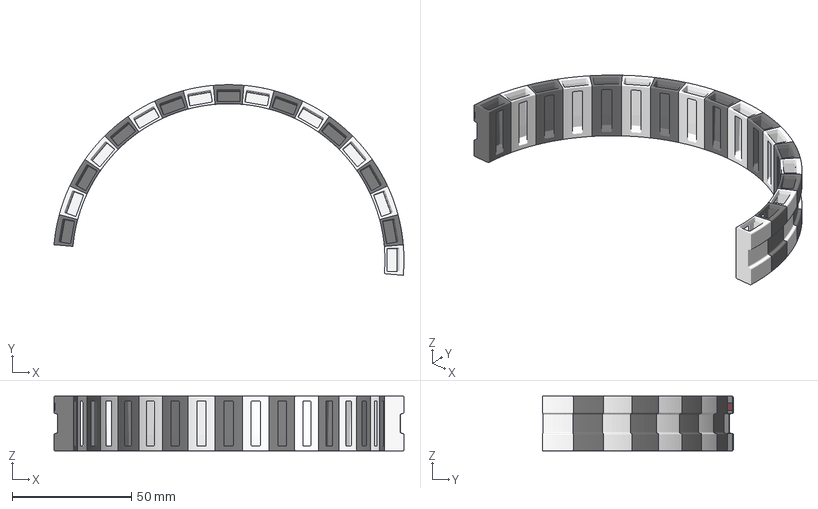
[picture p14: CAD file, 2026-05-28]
magnet_pocket/output/arc_ID131mm_18_36.3mf
146.7 x 79.9 x 23.0 mm
North
South
Index_Q
Index_H

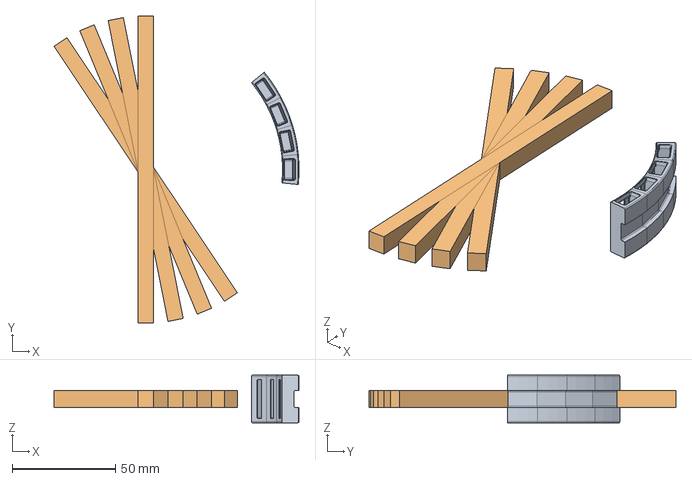
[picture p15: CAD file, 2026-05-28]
magnet_pocket/output/arc4_32.step
118.5 x 148.4 x 23.0 mm

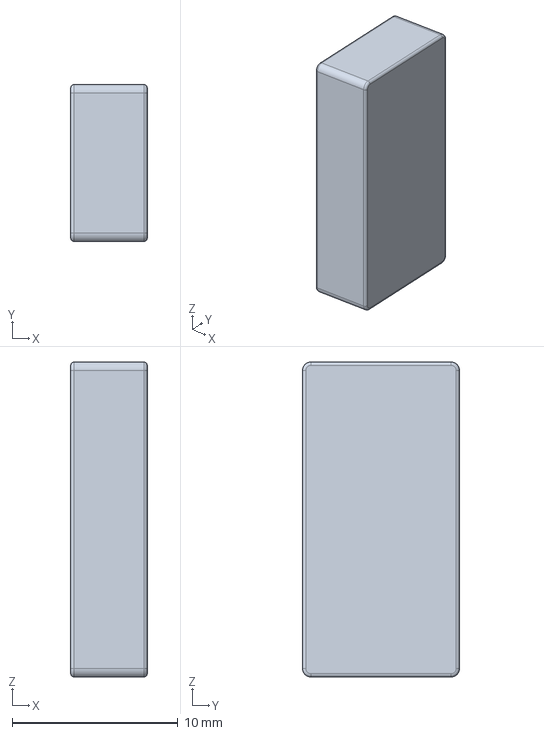
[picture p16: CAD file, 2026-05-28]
magnet_pocket/output/magnet.step
4.62 x 9.46 x 19.0 mm

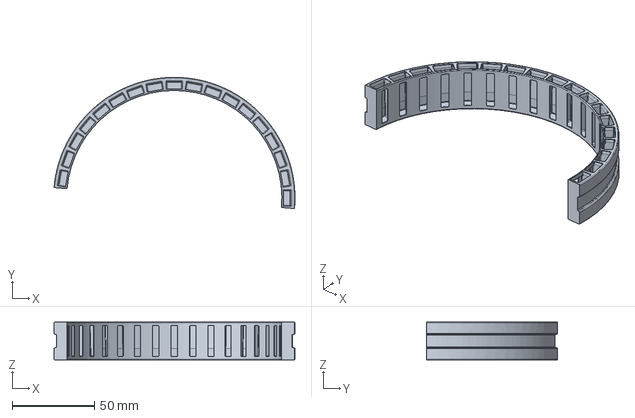
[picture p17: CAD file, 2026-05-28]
magnet_pocket/output/arc_ID131mm_18_36_fused.step
146.7 x 79.9 x 23.0 mm

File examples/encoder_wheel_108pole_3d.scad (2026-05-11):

// =============================================================================
//  Encoder Wheel Frame
//  Generated by generate_3d.py — do not edit by hand; re-run the script.
// =============================================================================
//
//  Render with F6 in OpenSCAD, then File → Export → STL.
//  Requires OpenSCAD 2021.01 or later.
//
//  Coordinate system
//  -----------------
//    Z = wheel axis (print flat on Z = 0 plane)
//    XY = wheel face
//

// ---- Geometry parameters ----------------------------------------
n_magnets       = 108;       // number of magnets
angle_step      = 3.333333; // degrees between magnets
magnet_length   = 20.0;    // radial length (mm)
magnet_width    = 5.0;     // tangential width (mm)
magnet_thick    = 2.0;     // axial thickness (mm)
r_inner         = 85.9194;  // inner radius (mm)
r_outer         = 105.9194;  // outer radius (mm)
r_frame         = 108.9194;  // frame outer radius (mm)
center_bore     = 5.0;     // shaft bore radius (mm)
clearance       = 0.15;    // per-side pocket clearance (mm)

// ---- Pocket dimensions ----------------------------------------
pw              = 5.3;   // pocket width  (tangential)
pl              = 20.3;   // pocket length (radial)
pd              = 2.0;       // pocket depth  (axial)
r_pkt           = 85.7694;  // pocket inner-edge radius

back_thickness  = 1.5;    // back plate thickness (mm)
tab_width       = 1.5;    // retaining tab radial width (mm)
tab_overhang    = 0.6;    // retaining tab overhang (mm)

z_back          = 1.5;    // Z of pocket floor
z_top_magnet    = 3.500;  // Z of pocket opening / magnet top
total_height    = 3.500;  // overall frame height

// ====================================================================
// Module: magnet_pocket()
// One magnet slot, open at the top face (+Z).
// In local coords: +Y = radial outward, +X = tangential CCW, +Z = axial.
// The pocket inner edge sits at r_pkt (slightly inside r_inner).
// ====================================================================
module magnet_pocket() {
    translate([-pw/2, 85.7694, 1.500])
        cube([pw, pl, pd + 1]);  // +1 ensures clean exit through top face
}

// ====================================================================
// Module: retaining_tabs()
// Two small lips at the inner and outer radial ends of the pocket
// opening.  They overhang the pocket so magnets snap in from above.
// Print with the pocket face upward so these bridge the gap.
// ====================================================================
module retaining_tabs() {
    // Inner-radial tab
    translate([-pw/2, 85.7694, 2.9000])
        cube([pw, 1.5, 1.6]);  // +1 = above face
    // Outer-radial tab
    translate([-pw/2, 104.5694, 2.9000])
        cube([pw, 1.5, 1.6]);
}

// ====================================================================
// Module: encoder_wheel()
// Complete encoder wheel frame — subtract pockets then optionally add
// tabs, front face, and/or steel clip slots.
// ====================================================================
module encoder_wheel() {
    union() {

        // -- Main body: outer ring + (optional) back disc --
        difference() {

            // Solid disc from z=0 to z=total_height
            cylinder(h = 3.500, r = r_frame, $fn = 128);

            // Central shaft bore
            cylinder(h = 3.500 * 3, r = center_bore, center = true, $fn = 64);


            // Magnet pockets
            for (i = [0 : n_magnets - 1]) {
                rotate([0, 0, i * angle_step])
                    magnet_pocket();
            }

        }  // end difference

        // -- Retaining tabs (overhang over pocket openings) --
        for (i = [0 : n_magnets - 1]) {
            rotate([0, 0, i * angle_step])
                retaining_tabs();
        }

    }  // end union
}  // end encoder_wheel

// ====================================================================
// Render the wheel
// ====================================================================
encoder_wheel();

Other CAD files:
examples/encoder_wheel_12pole_cnc.dxf
examples/encoder_wheel_108pole_cnc.dxf
examples/encoder_wheel_12pole_3d.scad
examples/encoder_wheel_12pole_3d_frontface.scad
examples/encoder_wheel_12pole_3d_steelclip.scad
examples/half_ring_cover.stl
magnet_pocket/output/arc18_36.3mf
magnet_pocket/output/arc_ID131mm_18_36_fused.3mf

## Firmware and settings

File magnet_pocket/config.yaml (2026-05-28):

# Magnet pocket generator configuration
magnet:
  radial_mm: 4.62   # 0.1819 inches
  tangential_mm: 9.46   # 0.3726 inches
  axial_mm: 19.0  # .7479 inches
  edge_radius_radial_mm: 0.5
  edge_radius_other_mm: 0.2
# These are the frame specs.
holder:
  material: PETG
  magnet_count: 36
  ID_mm: 131.0  # Inner diameter of the holder (bore diameter).
  thickness_mm: 8.0
  end_face_mm: 2.0
  clearance_mm: 0.1  # Each side will half of this clearance.
  inset_mm: 0.35  # Radial gap between bore (R_i) and pocket inner face.
# Tilted end-face insertion opening and lead-in frustum.
insertion:
  frustrum_depth_mm: 1.5  # how far back from the holder end face the frustum starts
  taper_len_mm: 5.0     # axial length of the lead-in taper
  taper_expand_mm: 1.0  # expansion per side for the lead-in taper
  cutter_z_mm: 5.0      # insertion cutter centre Z in cell frame
  rim_target_mm: 1.0    # inner rim thickness at the end face (bore side)

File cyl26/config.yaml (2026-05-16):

# CAD model: printed PETG cylinder that mounts on existing 4-in cast iron tube
# and holds 26 magnets.

# reference body only — existing cast iron tube, not printed
shaft:
  outer_radius_mm: 50.8

# printed PETG cylinder — bore fits over shaft OD
cylinder:
  material: PETG
  bore_clearance_mm: 0.1
  wall_mm: 6.0
  length_mm: 25.0

# 20x10x5 mm NdFeB N52 magnets
# axial = along sleeve axis (Z), tangential = around circumference, radial = through wall
magnet:
  count: 26
  axial_mm: 20.0
  radial_mm: 5.0
  tangential_mm: 10.0
  radial_rounding_mm: 0.5
  other_rounding_mm: 0.2
  pocket_clearance_mm: 0.1  # added to all pocket faces
  snap_lip_mm: 0.2          # lip thickness around bore-face opening

split:
  plane: xz  # Y=0; magnets must not intersect this plane

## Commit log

2026-05-11 Add encoder wheel design scripts, examples, images, and README
    - scripts/common.py: shared geometry (min inner radius formula, magnet corners)
    - scripts/generate_laser.py: generates SVG for laser cutting
    - scripts/generate_cnc.py: generates DXF R12 for CNC milling
    - scripts/generate_3d.py: generates OpenSCAD for 3D printing
    (tabs, back plate, front face, steel clip options)
    - examples/: pre-generated 12-pole and 24-pole examples
    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
    [encoder_wheel_12pole_3d.scad, encoder_wheel_12pole_3d_frontface.scad, encoder_wheel_12pole_3d_steelclip.scad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]
2026-05-11 Add 108-pole examples; fix pop() pattern and spelling in scripts
    - examples/encoder_wheel_108pole_laser.svg: 108-pole laser template
    (217.8 mm disc, 85.92 mm inner radius)
    - examples/encoder_wheel_108pole_cnc.dxf: 108-pole CNC DXF
    - examples/encoder_wheel_108pole_3d.scad: 108-pole 3D print SCAD
    - scripts/generate_3d.py: replace fragile list.pop() with clean conditional
    - scripts/generate_laser.py: fix 'centre' → 'center' for consistency
    - README.md: add 108-pole row to dimensions table and examples table
    Agent-Logs-Url: https://github.com/gfr10598/encoder-wheel/sessions/5b0c572f-e199-49d4-b143-cba5d005ef30
    [encoder_wheel_108pole_3d.scad, encoder_wheel_108pole_cnc.dxf]
2026-05-11 Add half-ring design docs and agent memory files
    Agent-Logs-Url: https://github.com/gfr10598/encoder-wheel/sessions/2a119013-0cdd-4ee1-966c-b69fd1ebbe7a
2026-05-11 Improve half-ring cross-section scaling and revise cover dimensions
    Agent-Logs-Url: https://github.com/gfr10598/encoder-wheel/sessions/60e2c704-c365-489c-b8b2-c10b4d0e4fad
2026-05-11 Adjust steel offset callout precision in cross-section docs
    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
2026-05-11 Plan update for 1/4in steel-capture wall requirement
    Agent-Logs-Url: https://github.com/gfr10598/encoder-wheel/sessions/dd8b474d-c8ee-4790-a3ce-45f46f2f1145
2026-05-11 Set steel-capture walls to 1/4in minus clearance
    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
2026-05-11 Fix cover to 5.75in ID / 8.25in OD; rewrite cross-section SVG; add build123d 3D model
    - generate_half_ring_docs.py: cover_wall = 1/8 in (was 1/4 in - 0.1 mm)
    giving 5.750 in ID / 8.250 in OD. Cross-section rewritten: base at top,
    true scale, walls at cover edges, snap on free ends of both capture walls.
    - scripts/generate_half_ring_3d.py: new build123d exporter producing
    examples/half_ring_cover.stl (base + inner/outer capture walls + snaps).
    - .gitignore: add negation rule so examples/*.stl is tracked.
    - Regenerated SVG documentation assets.
    [half_ring_cover.stl]
2026-05-11 Rewrite 3D model: component-based build123d with chamfer+snap walls
    [half_ring_cover.stl]
2026-05-11 Fix chamfer/snap geometry; refine cross-section SVG annotations
    [half_ring_cover.stl]
2026-05-12 Snap at steel seat (z3); magnets at outer edge; fix SVG zone fills
    - Swap snap/chamfer order: snap lip now at z3→z4 (0.2 mm at steel top),
    chamfer guide from z4→z5 (2 mm); total height z5=8.475 mm unchanged
    - Shift magnets to outer edge: mor=100.6 mm (1 mm from steel OD 101.6),
    mir=80.6 mm; inner stop wall 4.4 mm wide, outer stop 1.0 mm
    - Add make_magnet_end_walls(): printed radial stops sir→mir and mor→sor
    at z1→z2 height, fused into cover
    - Fix SVG magnet fill: blue rect now only spans mir→mor (not sir→sor)
    - Fix left Z-bracket labels: snap z3→z4, chamfer z4→z5
    - Fix snap callout leaders: point to z3→z4 level (steel top edge)
    [half_ring_cover.stl]
2026-05-12 Fix inner snap direction; add 0.2 mm magnet end clearance
    - Inner wall snap bead now protrudes INTO cavity (sir+snap) so it grips
    the steel ring's inner face; previously was going the wrong way outward
    - make_magnet_end_walls: pocket stop walls now leave 0.2 mm radial
    clearance each side (mir-0.2 inner, mor+0.2 outer) so magnets slide in
    - Add magnet_end_clearance=0.2 to design_data()
    [half_ring_cover.stl]
2026-05-12 Dogbones at snap roots + magnet corners; fix inner clearance to 0.1 mm
    - Snap-root dogbone groove (0.25 mm) added to inner and outer wall XZ
    profiles: slot undercuts PETG wall at z3-r_dog so snap tooth can flex
    - make_magnet_pocket_dogbones(): 0.25 mm axial cylinders at all 4 corners
    of every magnet slot (inner and outer pocket wall × both angular ends),
    subtracted from cover; enables full magnet seating without interference
    - magnet_end_clearance reduced to 0.1 mm (inner PETG = 4.3 mm exactly)
    - dogbone_radius = 0.25 mm added to design_data()
    [half_ring_cover.stl]
2026-05-12 Subtractive cover model: blank annulus → cut steel cavity + magnet pockets
    - Entirely replace additive multi-fuse approach with CSG subtraction:
    blank semi-annulus (cir→cor, z0→z5) → cut steel_cavity_void →
    cut each of 45 magnet_pocket_voids → cut dogbone cylinders
    - make_steel_cavity_void(): revolves full steel seat + snap beads + chamfer
    in one shot with 0.05 mm clearance on all faces
    - make_magnet_pocket_void(): per-magnet Box with 0.05 mm clearance each side
    - make_magnet_dogbones(): 0.25 mm cylinders at all 4 base corners of every
    magnet pocket (inner/outer radial face × both angular ends), spanning z=0→z2
    - First magnet now at angle 0° (Y=0 midplane) so cross-se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
2026-05-12 O-ring torus dogbones at steel corners + magnet pocket radial faces; fix ref magnet z-position
2026-05-12 Dogbones attached to pocket voids; snap-root tori below z3; STEP default output
    - make_magnet_pocket_void(): fuse 4 dogbone cylinders (r=0.25mm) into
    each pocket void before cutting — dogbones span z1→z2+0.05 only,
    never below z1 so the 1mm base skin is untouched
    - make_snap_root_dogbones(): half-torus at (sor-snap, z3-r) and
    (sir+snap, z3-r) — torus centred at z3-r so entire body sits below
    the snap arm, creating hinge relief without cutting into the tooth
    - make_steel_corner_dogbones(): floor z corrected to z2-0.05 (actual
    cavity floor level)
    - Remove make_magnet_pocket_dogbones() (superseded by per-void approach)
    - generate_half_ring_3d.py: --step flag replaced by --no-ste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
    [half_ring_cover.step]
2026-05-12 Corner rounds on ref bodies; pocket dogbones as Compound; snap tori on steel face; PETG bevels
    - make_single_magnet(): 0.7mm corner rounds on 2mm (Z) edges, 0.3mm on
    longer edges — models real sintered magnet geometry
    - make_steel_half_ring(): 0.5mm corner rounds on all edges
    - make_magnet_pocket_void(): replace sequential void.fuse() calls with
    Compound([box_void] + cyl_shapes) — avoids boolean-on-void failure
    - make_snap_root_dogbones(): tori now centred on steel face (sor/sir),
    not snap edge — groove at the correct PETG wall transition point
    - make_cover(): 0.2mm chamfer (bevel) on circular exterior arcs at z=0
    and z=z5; Y=0 boundary edges excluded to avoid single-face OCCT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
    [half_ring_cover.step]
2026-05-12 Fix pocket void cut + magnet fill position in cross-section
    - make_magnet_pocket_void(): build box and 4 dogbone cylinders inside a
    single BuildPart context so they auto-fuse into one solid before being
    used as the CSG cutter — Compound([...]) was silently not cutting
    - generate_half_ring_docs.py: magnet reference fill moved to z2-mt→z2
    (matches actual placement hanging from steel bottom face), not z1→z1+mt
2026-05-12 Add floor-edge horizontal dogbones to magnet pocket void
    Each pocket void now has 8 dogbone cylinders in addition to the 4
    vertical corner cylinders:
    - 2 along each long wall (Y = ±W/2), running radially (X axis)
    - 2 along each short wall (X = 0 and X = L), running tangentially (Y axis)
    Each horizontal cylinder is centred at z = r_dog above the pocket floor
    so the groove bottom is tangent to z=0 — no material removed below the
    floor, preserving the 1 mm base skin.
    [half_ring_cover.step]
2026-05-12 Steel seats flush (zero axial clr); 0.05mm side clr; grey bg + black 0.02mm outlines
    3D model:
    - make_steel_cavity_void: floor at z2 (was z2-0.05) — steel seats flush
    - make_steel_corner_dogbones: z_floor = z2 to match
    - magnet void position is unchanged; moves with steel (it was always at z1→z2)
    Cross-section SVG:
    - Background rect changed from white to #e8e8e8 (light grey)
    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
    [half_ring_cover.step]
2026-05-12 Fix steel radial clearance; add pocket entry chamfer; SVG corner rounds
    - make_steel_cavity_void: cavity walls now at sir-0.05 / sor+0.05 (were
    sir+0.05 / sor-0.05 — negative clearance; steel couldn't enter)
    - make_steel_corner_dogbones: tori updated to match sir-0.05 / sor+0.05
    - make_magnet_pocket_void: 0.5 mm high × 0.2 mm wide entry chamfer added
    at pocket opening (z=T face) to guide magnet into alignment on insertion
    SVG cross-section:
    - rect() helper now nested inside generate_cross_section_svg (was
    accidentally promoted to module scope, breaking the function)
    - Magnet and steel reference rects get rx=0.3 rounded corners to reflect
    their real deburred/chamfered ge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
    [half_ring_cover.step]
2026-05-12 Fix blue shadow: magnet clearance zone now z1→z2, magnet rect z2-mt→z2
2026-05-12 Remove light-blue magnet clearance zone rect from cross-section SVG
2026-05-12 Steel reference: chamfer 0.25mm (was 0.5mm fillet); SVG rx=0.15
    [half_ring_cover.step]
2026-05-12 Pocket entry frustum: base at z=T-ch_h (L×W), expands to z=T
    Chamfer starts 0.5mm below pocket top with base sized exactly to the
    pocket opening (L×W). Negative taper expands outward 0.2mm/side going
    up to z=T, cutting into the walls — correct lead-in for magnet insertion.
    Previously the frustum was placed at z=T going upward, which added void
    above the pocket rather than chamfering the entry walls.
2026-05-12 Regenerate SVGs, STL, STEP after pocket entry chamfer + steel ref chamfer
2026-05-13 Add magnet-field simulator and example config (sweepable magnet/airgap analysis)
2026-05-13 Fix analytic default: revert use_gemini to False; add geometry validation test
    - Changed analytic_rect_prism_B() default from use_gemini=True back to False
    - Gemini has inverted sign convention; algebraic method is correct and matches numeric
    - Analytic magnitude differences (10-20% vs dipole) are due to rectangular magnet
    extent effects, not bugs—physically correct behavior requiring geometry-aware models
    - Added test_geometry_consistency.py for method validation
    - Updated AGENTS.md with corrected reconciliation explanation
    [n52_20x8x1.5_60_outer4in_sensor3p8in_fine.yaml]
2026-05-13 Fix raw_B plots: show By (tangential) and Bz (axial) instead of radial
    - Changed plot axes from Bx (radial) + By to By + Bz to match encoder sensor geometry
    - Sensor positioned axially above disk, so By/Bz components are physically relevant
    - Added matplotlib.use('Agg') backend to fix multiprocessing plot generation
    - Note: ProcessPoolExecutor parallelism issue remains to be diagnosed
2026-05-13 Switch from ProcessPoolExecutor to sequential processing
    - ProcessPoolExecutor multiprocessing was hanging with <1 core utilization
    - Sequential processing verified to work correctly (test_single_airgap completed)
    - Removes multiprocessing bottleneck while maintaining correctness
    - Trade-off: slower but reliable until parallelism is fixed
2026-05-13 Fix energy display to show By/Bz ratio instead of discrete/analytic ratio
    - Energy box now shows By/Bz ratio for both methods (encoder signal vs pole field energy)
    - Added vertical lines marking expected peaks (3°, 9°) and zeros (0°, 6°, 12°)
    - Shows actual peaks ~1.5° early (8.5° instead of 9°) - likely due to sensor radial offset
    - Both discrete and analytic methods agree on phase; offset comes from geometry, not method
    - Discrete and single-dipole methods produce nearly identical results
    [n52_20x8x1.5_60_outer4in_sensor3p8in_coarse.yaml]
2026-05-13 Regenerate all 16 airgap plots with vectorized computation, dual-method comparison, and energy metrics
    - Vectorized theta loop using numpy broadcasting (250× speedup per airgap)
    - Discrete method: 40×16×3 sub-dipole grid with pre-computed cos/sin
    - Analytic method: rectangular prism corner-sum formulation
    - Plot features:
    * By/Bz energy ratio display (encoder signal vs pole field)
    * Expected peak markers (3°, 9°) and zeros (0°, 6°, 12°) visualization
    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
2026-05-13 Document vectorization, parallelization, and asymmetry issue in AGENTS.md
    - Recorded 250× speedup from vectorized computation (29.5M calcs → 4–5 sec/airgap)
    - Documented 4-job parallel runner: 27.6 sec for all 16 airgaps
    - Identified discrete method asymmetry as likely geometry bug in rotation transform
    - Logged next investigation steps: audit discretize_block() in analysis_utils.py
2026-05-15 Delete old field calculation code with coordinate transform bugs
    Remove deprecated implementations:
    - analysis_utils.py (bad coordinate transforms, 32% error root cause)
    - magnet_transform.py (disk-center rotation causing component swap)
    - numeric_analysis.py, highres_numeric.py (old discrete methods)
    - coords.py, vector_utils.py (old transform utilities)
    - validate_analytic.py, simple_single_magnet_test.py (old test approach)
    - check_*.py, fresh_field_calc.py (debugging artifacts)
    - plot_results.py, offsym_compare.py (analysis-only scripts)
    - gemini-field-formula.py (external reference, no longer needed)
    - run_parallel_analysis.py, run_all_airgaps.sh (old runners)
    Keep validation tests (co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
    [n52_20x8x1.5_60_outer4in_sensor3p8in_fine.yaml]
2026-05-15 Fix: double-flip bug in analytic rect prism—sensor frame transform now correct
    Root cause: Sensor position transformation to magnet-local coordinates was
    being applied twice, flipping the sign incorrectly.
    Changes:
    - Remove duplicate magnet-local coordinate transform in analytic_rect_prism_B()
    - Apply transform only once: global → magnet-local, compute field, then back
    - Update test expectations based on correct field symmetry
    Verification:
    - Z-axis: Bz=0 at all heights by 4-fold symmetry ✓
    - Cardinal points: Bθ=0 by azimuthal symmetry ✓
    - Diagonals: Br=0 by 4-fold symmetry, Bθ non-zero ✓
    - test_symmetry_sanity_check.py: ALL TESTS PASSED
2026-05-15 Refactor: MagnetCorners now stores and uses Br_T values per corner
    - Rename mu_values → br_values (remanent flux density in Tesla)
    - Update __init__, __repr__, combine(), add() to use br_values
    - compute_field_at() now gets Br values from corners, not as parameter
    - magnet_to_corners() now takes Br_T parameter and computes corner Br values
    - array_to_corners() also takes Br_T parameter
    - Add compute_field_analytic() static method for single rectangular magnet
    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
2026-05-15 Fix: test_single_magnet_vs_kj now uses correct 10x5x1 magnet and K&J validation (1.6% error)
2026-05-15 Add: analysis utilities and magnet signal analysis script
2026-05-15 Refactor: Separate CAD and magnetic analysis scripts into subdirectories
    Moves:
    - scripts/cad/: generate_laser.py, generate_cnc.py, generate_3d.py,
    generate_half_ring_3d.py, generate_half_ring_docs.py
    - scripts/magnetic/: magnet.py, analysis_utils.py, field.py, sensor.py,
    simulation.py, and all test files (test_*.py)
    - scripts/ root: common.py, common_config.py (shared across both)
    Updated imports in magnetic files to reference modules from new location.
    All tests passing (K&J validation: 1.6% error).
2026-05-15 Fix symmetry sanity check to use Br_T terminology consistently
    - Remove all mu references from test output
    - Use explicit Br_T values in magnet configs
    - Clear corner Br assignments: upper surface and lower surface labeled with actual Br_T
    - Verify 4-fold symmetric cross geometry and field patterns
    - All assertions pass: Z-axis Bz=0, cardinals have azimuthal symmetry, diagonals have radial cancellation
2026-05-15 Add arc-ring magnetic simulator and 4" tube magnet configs
    New simulation infrastructure:
    - magnet_vec.py: MagnetCornersVec with arbitrary Br direction vector (radially-
    magnetized arc magnets); Aharoni rectangular-prism formula; verified against
    dipole limit and multi-axis rotation
    - magnet_transform.py: rotation helpers for magnet-local ↔ global coordinates
    - plot_arc_ring.py: config-driven arc-ring field sweep, per-radius waveform plots
    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
2026-05-16 starting 26 magnet cylinder
2026-05-16 cyl26: magnet pocket with snap-in opening via CSG
    - Pocket derived from magnet body via offset(cl/2), centre shifted outward
    by cl/2 so inner faces of pocket, magnet, and shaft all align at 50.8 mm
    - Snap opening: plain box (magnet dims minus 2×snap_lip on tang/axial),
    centred 2 mm inward from magnet centre, gives 0.2 mm lip at bore face
    - Config migrated to hierarchical YAML; snap_lip_mm added to magnet section
    - Magnet reference body rendered opaque (alpha=1.0) to avoid Three.js
    depth-sort artifact when sleeve is transparent
    [config.yaml]
2026-05-17 pretty good shaft ring design
2026-05-24 magnet pocket angular slice
2026-05-25 snap in teeth
    [cell.step, magnet.step]
2026-05-25 end insertion pocket
    [cell.step, magnet.step]
2026-05-26 thicker bottom support.
    [cell.step, magnet.step]
2026-05-26 tighter tolerances
    [cell.step, magnet.step]
2026-05-26 move tilt further out.
    [cell.step, magnet.step]
2026-05-28 fused option to avoid multi-part problems in slicer
    [arc16_32.step, arc18_36.3mf, arc18_36.step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]
2026-05-29 add snaps and hole
2026-05-29 fillet the push down hole
2026-06-05 working on 5bit/sample encoder
